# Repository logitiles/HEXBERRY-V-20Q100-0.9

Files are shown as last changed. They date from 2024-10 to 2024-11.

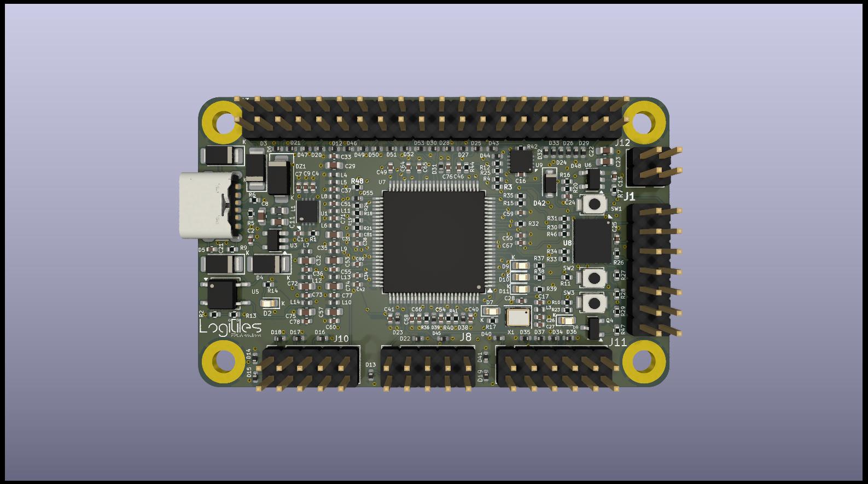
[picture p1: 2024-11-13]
3D e CAM/HEXBERRY-V-20Q100-3D1.jpg

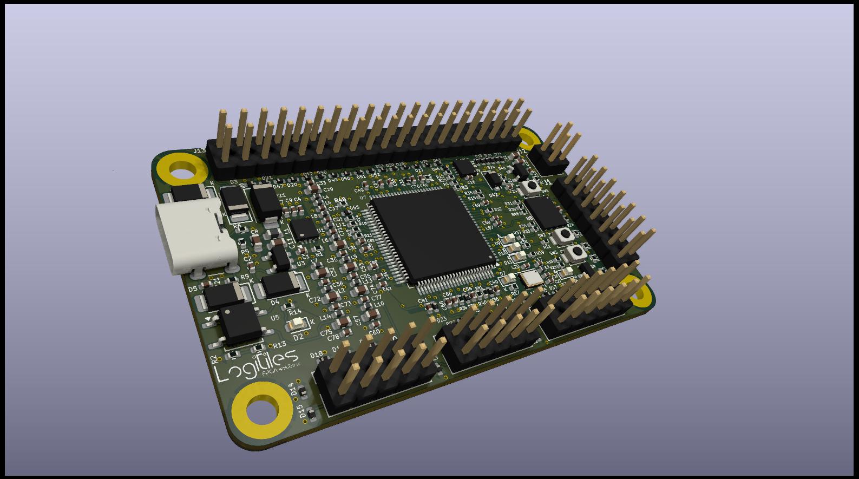
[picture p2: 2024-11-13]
3D e CAM/HEXBERRY-V-20Q100-3D2.jpg

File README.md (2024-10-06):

### <div align="center">We are the [LOGITILES](http://www.logitiles.com), a passionate, full-time FPGA platforms developers team.</div>

- We’re currently working on [HEXCAPE-V Open Source FPGA platform](https://www.hexberryv.eu)

- We’re also currently providing VHDL and VERILOG training and courses for professionals and
 employees.

- Please visit our [Website platform](https://www.logitiles.com)

<br/>

## Our Skill Set
<table><tr><td valign="top" width="33%">

### Electronics design
<div align="center">
<a href="https://www.kicad.org" target="_blank">Kicad</a>
</div>

</td><td valign="top" width="33%">

### Firmware languages & tools
<div align="center">
<a href="https://www.android.com/" target="_blank">Android</a>
<a href="https://www.arduino.cc/" target="_blank">Arduino</a>
<a href="https://www.bell-labs.com/usr/dmr/www/chist.html" target="_blank">C</a>
<a href="https://en.wikipedia.org/wiki/C_Sharp_(programming_language)" target="_blank">C#</a>

<a href="https://dart.dev/" target="_blank">Dart</a>

<a href="https://www.djangoproject.com/" target="_blank">Django framework</a>

<a href="https://go.dev/" target="_blank">Go</a>

<a href="https://simple.wikipedia.org/wiki/JavaScript/" target="_blank">Javascript</a>

<a href="https://kotlinlang.org/" target="_blank">Kotlin</a>

<a href="https://www.opencv.org" target="_blank">OpenCV</a>
<a href="https://pytorch.org" target="_blank">Pytorch</a>

<a href="https://www.raspberrypi.com/" target="_blank">Raspberry PI</a>

<a href="https://www.scala-lang.org/" target="_blank">Scala</a>

<a href="https://www.tensorflow.org" target="_blank">Tensorflow</a>

<a href="https://www.cplusplus.com/" target="_blank">C++</a>
<a href="https://www.javascript.com/" target="_blank">JavaScript</a>
<a href="https://www.php.net/" target="_blank">PHP</a>
<a href="https://www.linux.org/" target="_blank">Linux</a>
<a href="https://www.python.org/" target="_blank">Python</a>
<a href="https://github.com/" target="_blank">Git</a>

</div>

</td><td valign="top" width="33%">

### Fpga brands
<div align="center">
<a href="https://www.altera.com/" target="_blank">Altera</a>

<a href="https://www.amd.com/en/products/adaptive-socs-and-fpgas/fpga.html" target="_blank">Amd</a>

<a href="https://www.latticesemi.com" target="_blank">Lattice semiconductors</a>

<a href="https://www.microchip.com/en-us/products/fpgas-and-plds/fpgas" target="_blank">Microchip</a>

<a href="https://www.efinixinc.com" target="_blank">Efinix</a>

<a href="https://www.sw.siemens.com/" target="_blank">Mentor</a>

<a href="https://www.aldec.com" target="_blank">Aldec</a>

</div>

</td></tr></table>

<br/>

## Connect with us
<div align="center">
<a href="https://x.com/logitiles" target="_blank">

</a>
<a href="https://www.linkedin.com/in/pierfrancescomariasanti/" target="_blank">

</a>
<a href="https://instagram.com/logitiles" target="_blank">

</a>
<a href="https://www.youtube.com/@logitiles-k9s" target="_blank">

</a>
</div>

<br/>

## Github Stats


<br/>

## Recent Blog Posts
<!-- BLOG-POST-LIST:START -->
If things goes well, this section should automatically be replaced by a list of your blog posts after you commit your readme file.
<!-- BLOG-POST-LIST:END -->

<br/>

<br/>

<div align="center">

</div>

<br/>

<br />

----

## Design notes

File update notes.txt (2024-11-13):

 
0.90 to 0.91 vers  (2024/11/13)

- metallized holes to be put in place of the non-metallic ones
- K (cathode) on D1 placed near the other pad
- U1: put pin 3 at 5V and not at PWR_EN
- add 10K pull-up on RESET_N of U6
- reduce R16 to 10k
- put 10K between VCCIO1A_1B_1C and CDONE

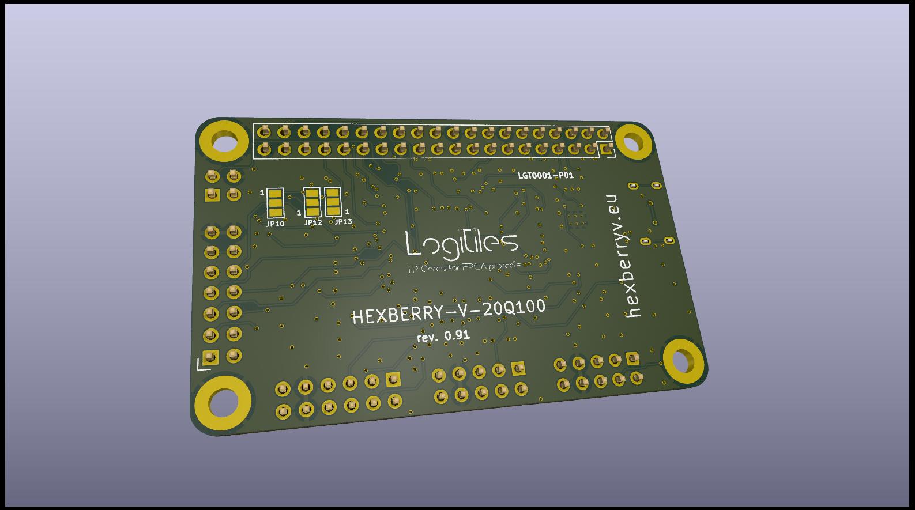
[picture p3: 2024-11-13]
3D e CAM/HEXBERRY-V-20Q100-3D4.jpg

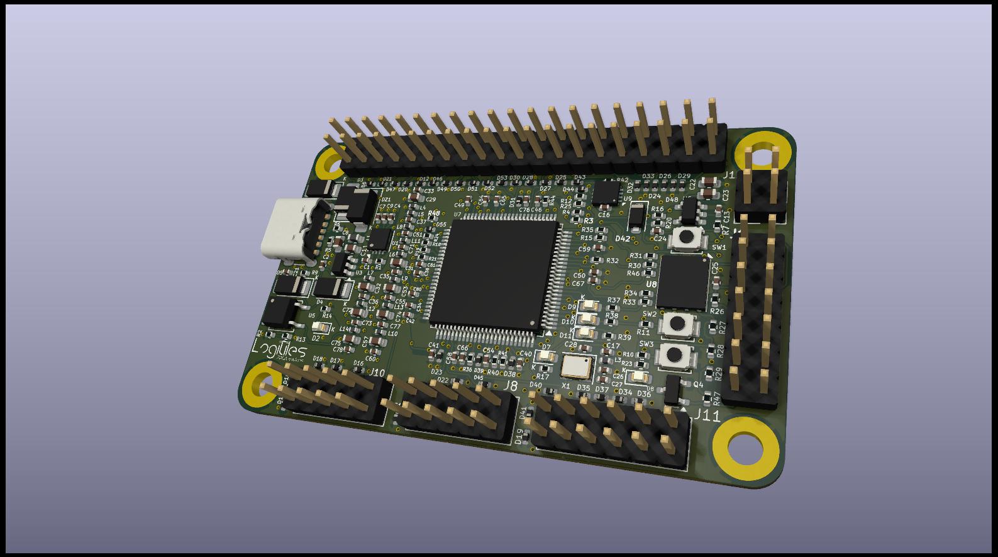
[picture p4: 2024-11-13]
3D e CAM/HEXBERRY-V-20Q100-3D3.jpg

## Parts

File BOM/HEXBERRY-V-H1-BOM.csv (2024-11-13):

Reference | Value | Footprint | Qty | Manufacturer | I° source code | price I° source | II° source code | price II° source
C1,C2,C7,C33,C35,C36,C37,C51,C55,C60,C71,C73,C77,C78 | 1uF | Capacitor_SMD:C_0402_1005Metric | 14 | SAMSUNG | L C14445 | € 0.0016
C4,C9,C13,C16,C17,C21,C25(DNP),C27,C34,C38,C40,C41,C42,C46,C49,C50,C54,C58,C59,C64,C65,C66,C67,C76,C80,C81 | 0.1uF | Capacitor_SMD:C_0402_1005Metric | 25 | CCTC | L C392963 | € 0.0009
C8,C11,C22,C23,C29,C31,C32,C53,C57,C72,C74,C75 | 10uF | Capacitor_SMD:C_0603_1608Metric | 12 | SAMSUNG | L C19702 | € 0.0051
C24 | 0.01uF | Capacitor_SMD:C_0402_1005Metric | 1 | SAMSUNG | L C15195 | € 0.0012
C26,C28 | 4.7uF | Capacitor_SMD:C_0402_1005Metric | 2 | SAMSUNG | L C23733 | € 0.0049
D1,D3,D4, D5 (DNP) | STPS360AF | Diode_SMD:D_SOD-128 | 3 | ST | L C5268312 | € 0.2213 | M 511-STPS360AF
D2,D8 | LS Q976.01-N1Q2-1 | LED_0603 GIALLO VERDE | 2 | YONGYUTAI | L C22371297 | € 0.0076
D11,D10,D9 | LS Q976.01-N1Q2-1 | LED_0603 BLUE | 3 | YONGYUTAI | L C19171394 | € 0.0049
D7 | LS Q976.01-N1Q2-1 | LED_0603 ROSSO | 1 | YONGYUTAI | L C19171390 | € 0.0049 | M 720-LSQ976.01-N1Q2-1
D6,D12,D13,D14,D15,D16,D17,D18,D19,D20,D21,D22,D23,D24,D25,D26,D27,D28,D29,D30,D31,D32,D33,D34,D35,D36,D37,D38,D39,D40,D41,D43,D44,D45,D46,D47,D48,D49,D50,D51,D52,D53,D55 | CPDQC3V3C-HF | diodo_mio:D_0402_1005Metric | 43 | LEIDITECH | L C5128403 | € 0.019
D42 | SOD4007-MS | Diode_SMD:D_SOD-123F | 1 | MSKSEMI | L C3008061 | € 39,00
DZ1 | SMAJ6.5CA/TR13 | Diode_SMD:D_SMA | 1 |  | L C2926834 | € 0.035
J1 | Conn_02x07_Odd_Even | Connector_PinSocket_2.54mm:PinSocket_2x07_P2.54mm_Vertical | 1
J2 | DEALON USB-TYPE-C-010 | Connector_USB:USB_C_Receptacle_GCT_USB4125-xx-x-0190_6P_TopMnt_Horizontal | 1 | DEALON | L C2927030 | € 0.0312
J8,J10 | Conn_02x05_Odd_Even | Connector_PinSocket_2.54mm:PinSocket_2x05_P2.54mm_Vertical | 2
J11 | Conn_02x06_Odd_Even | Connector_PinSocket_2.54mm:PinSocket_2x06_P2.54mm_Vertical | 1
J12 | Conn_02x02_Odd_Even | Connector_PinHeader_2.54mm:PinHeader_2x02_P2.54mm_Vertical | 1
J13 | ZERO 40pin CONN | Connector_PinSocket_2.54mm:PinSocket_2x20_P2.54mm_Vertical | 1
L1 | 33Ohm 4A | Inductor_SMD:L_0603_1608Metric | 1 | Murata | L C98303
L3,L4,L5,L6,L7,L8,L9,L10,L11,L12,L13,L14 | BLM15AX601SZ1D | Inductor_SMD:L_0402_1005Metric | 12 | Murata | L C76886 | € 0.006
Q4 | MMUN2211LT1G | Package_TO_SOT_SMD:SOT-23 | 1 | Onsemi | L C55059 | € 0.0225
R1,R2,R5,R6,R12,R13,R25 | 5K1 | Resistor_SMD:R_0402_1005Metric | 7 | UNI ROYAL | L C25905 | € 0.0005
R9,R20 | 330R | Resistor_SMD:R_0402_1005Metric | 2 |  | L C25104 | € 0.0006
R7, R10, R11, R15, R16, R18, R21, R26, R27, R28, R29, R40, R41, R46, R47, R48, R19(DNP), R31(DNP), R32(DNP), R33(DNP), R34(DNP), R35(DNP) | 10K | Resistor_SMD:R_0402_1005Metric | 16 | YAGEO | L C60490 | € 0.0005
R14,R17,R23,R24,R37,R38,R39 | 1K | Resistor_SMD:R_0402_1005Metric | 16 |  | L C11702 | € 0.0005
R3(DNP),R4(DNP),R30,R42,R44 | 0R0 | Resistor_SMD:R_0402_1005Metric | 17 | UNI ROYAL | L C21376 | € 0.0004
R36 | 100R | Resistor_SMD:R_0402_1005Metric | 19 |  | L C25076 | € 0.0005
SW1,SW2,SW3 | TACT_SW | Button_Switch_SMD:SW_SPST_B3U-1000P | 20 |  | L C231329 | € 0.13 | M 653-B3U-1000P | € 0,91
U1 | MCP1725T-1202E/MC | Package_DFN_QFN:DFN-8-1EP_3x3mm_P0.5mm_EP1.65x2.38mm_ThermalVias | 21 |  | L C623071 | € 0.57 | M 579-MCP1725T-1202EMC | € 0,66 | D MCP1725T-1202E/MCCT-ND | € 0.65
U3 | SPX3819M5-L-3-3 | Package_TO_SOT_SMD:SOT-23-5 | 22 |  | L C20617301 | € 0,076
U5 | GAQY212GSX | Package_SO:SOP-4_3.8x4.1mm_P2.54mm | 23 |  | L C19271988 | € 0.4191
U6 | TLV840MADL13DBVR | Package_TO_SOT_SMD:SOT-23-5 | 24 |  | L C1518734 | € 0.5085 | M 595-TLV840MADL13DBVR | € 0,66 | D 296-TLV840MADL13DBVRCT-ND | € 0.51
U7 | T20Q100F3C3 | Package_QFP:LQFP-100_14x14mm_P0.5mm | 25 |  | D 2134-T20Q100F3C3-ND | € 8.5
U8(DNP) | W25Q32JVUUIQ | Package_SON:WSON-8-1EP_4x4mm_P0.8mm_EP1.98x3mm | 26 |  | L C2999380 | € 0.42 | M 454-W25Q32JVXGIQTR | € 0,79
U9 | ATSHA204A-MAHDA-T | Package_DFN_QFN:TDFN-8-1EP_3x2mm_P0.5mm_EP1.4x1.4mm | 27 |  | L C461613 | € 0.7052 | M 566-ATSHA204AMAHDA-T0,52 € | € 0,52 | D ATSHA204A-MAHDA-TCT-ND | € 0.52
X1 | ASE-50.000MHz-ET | Oscillator:Oscillator_SMD_Abracon_ASE-4Pin_3.2x2.5mm | 28 |  | L C5885439 | € 0.24 | 535-ASE-50.000MHZ-E-TCT-ND | € 0,85 | D 535-ASE-50.000MHZ-E-TTR-ND | € 0.85
LEGEND:
L: LCSC
D: DIGIKEY
M: MOUSER

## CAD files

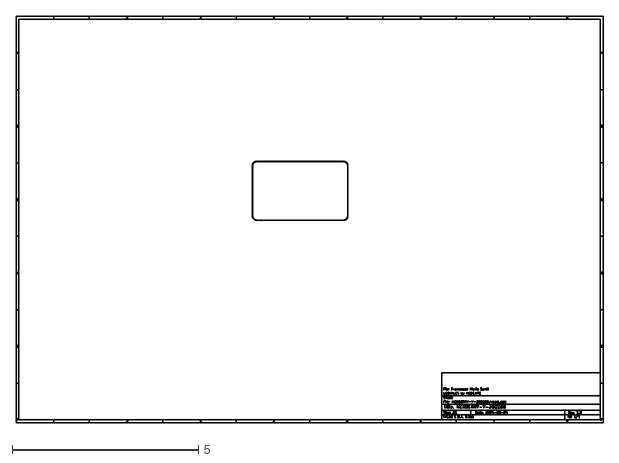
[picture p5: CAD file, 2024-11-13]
PM/STENCIL/HEXBERRY-V-20Q100-Edge_Cuts.dxf
15.7 x 10.9

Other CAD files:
PM/STENCIL/HEXBERRY-V-20Q100-F_Paste.dxf

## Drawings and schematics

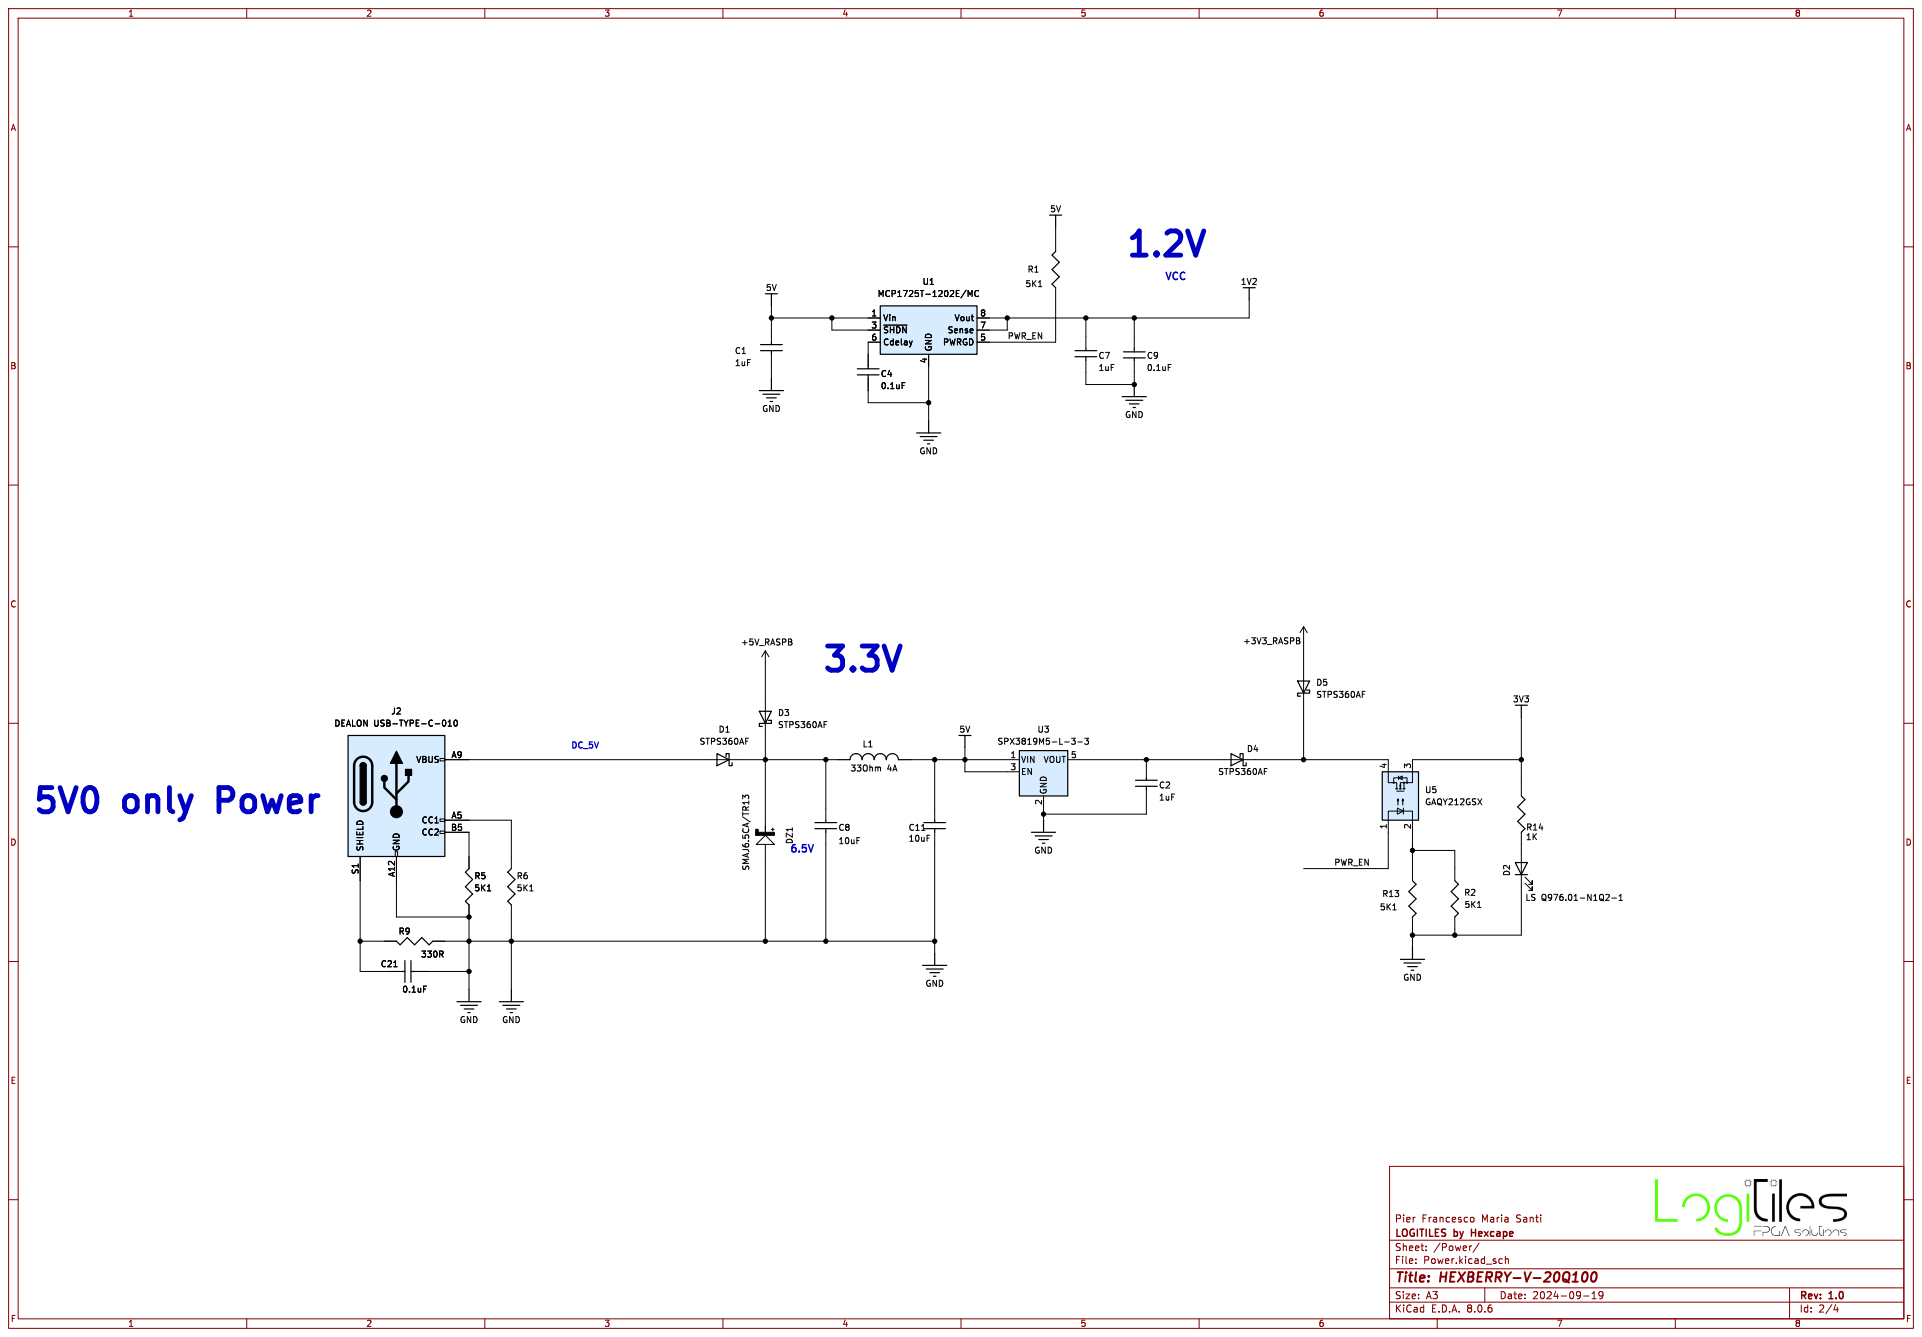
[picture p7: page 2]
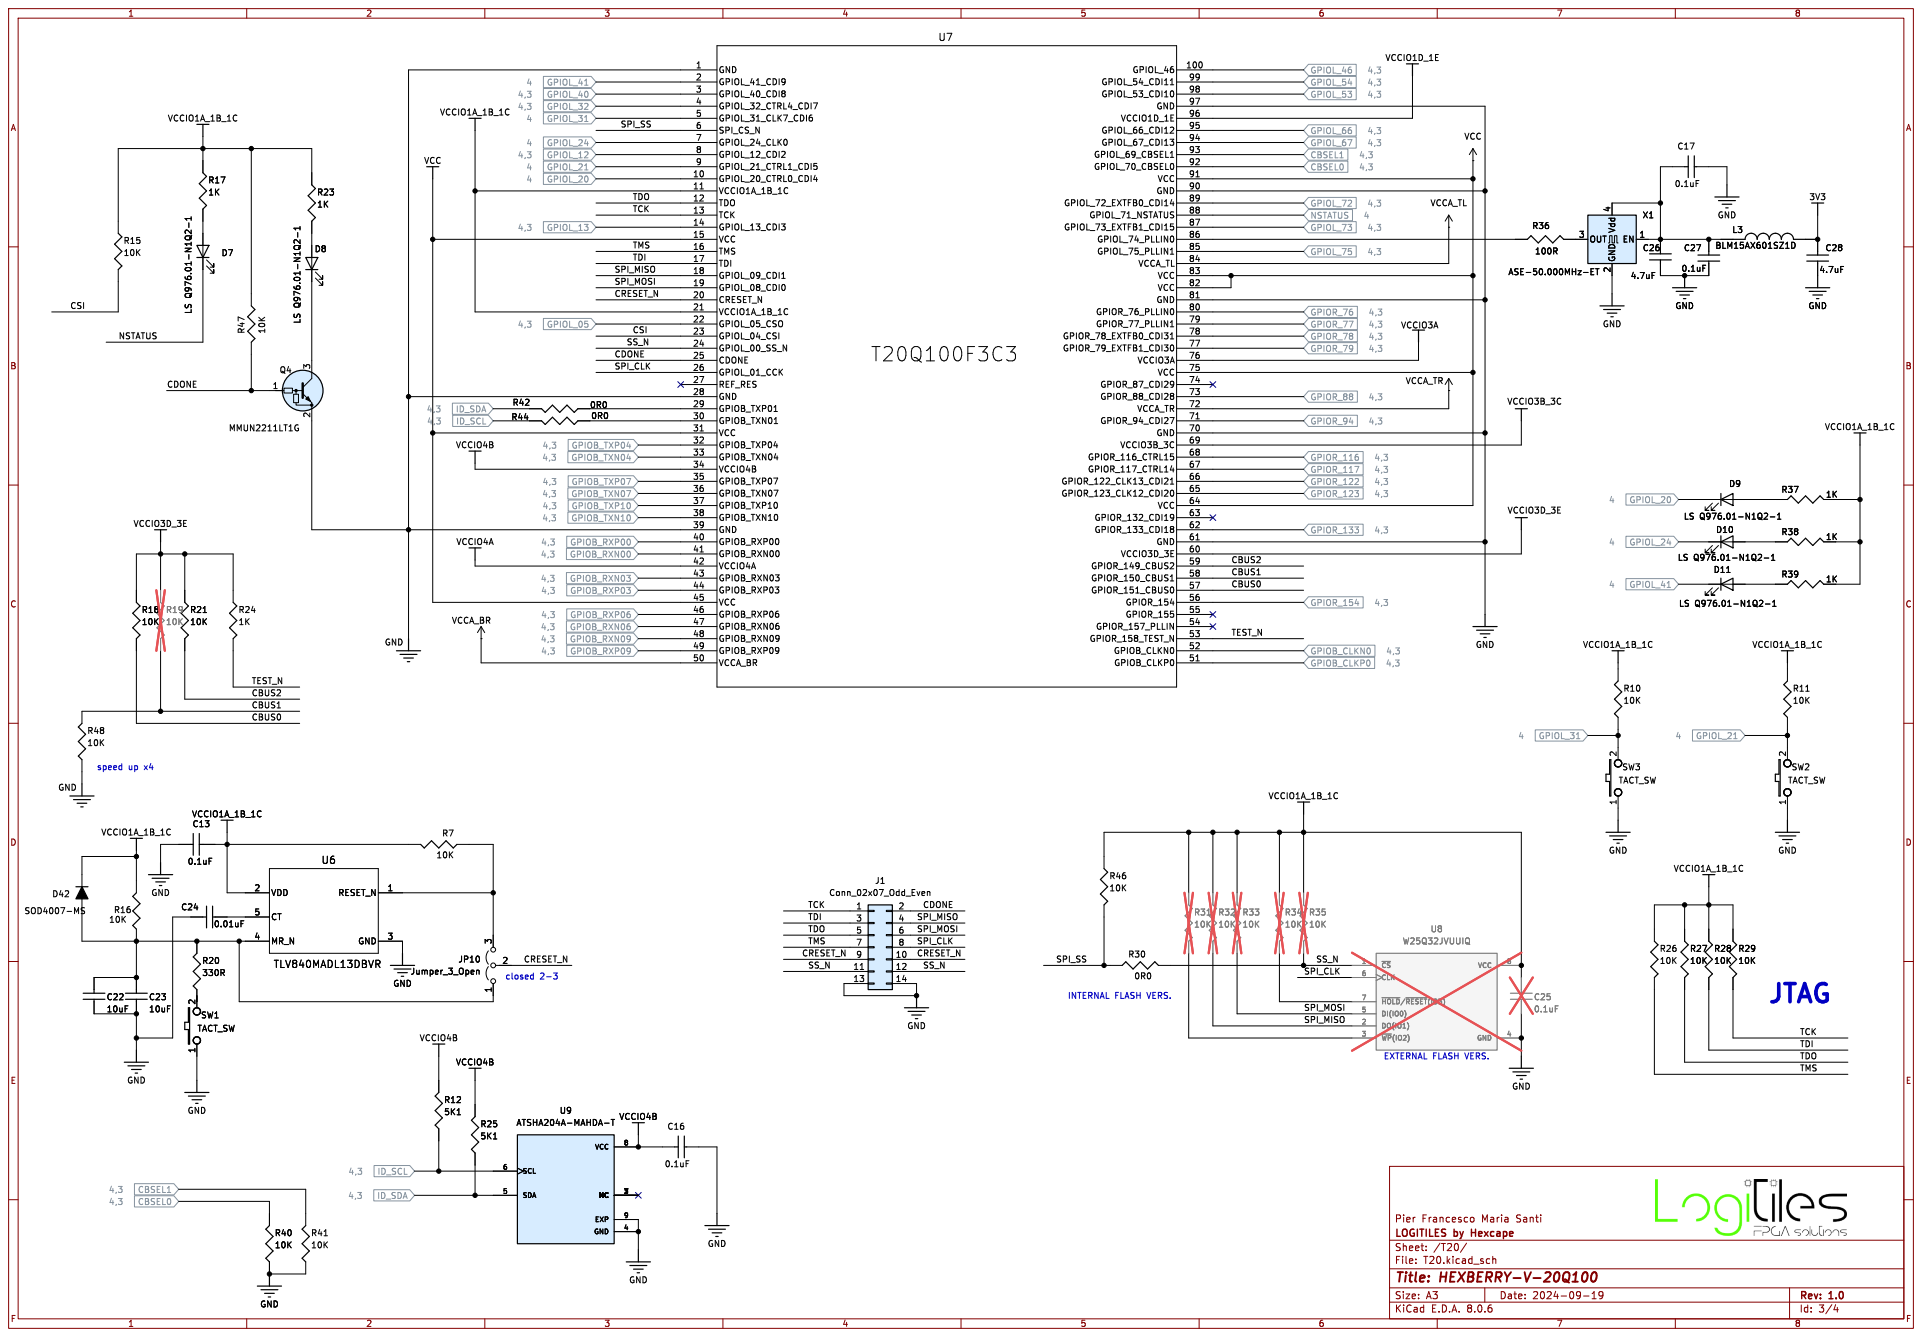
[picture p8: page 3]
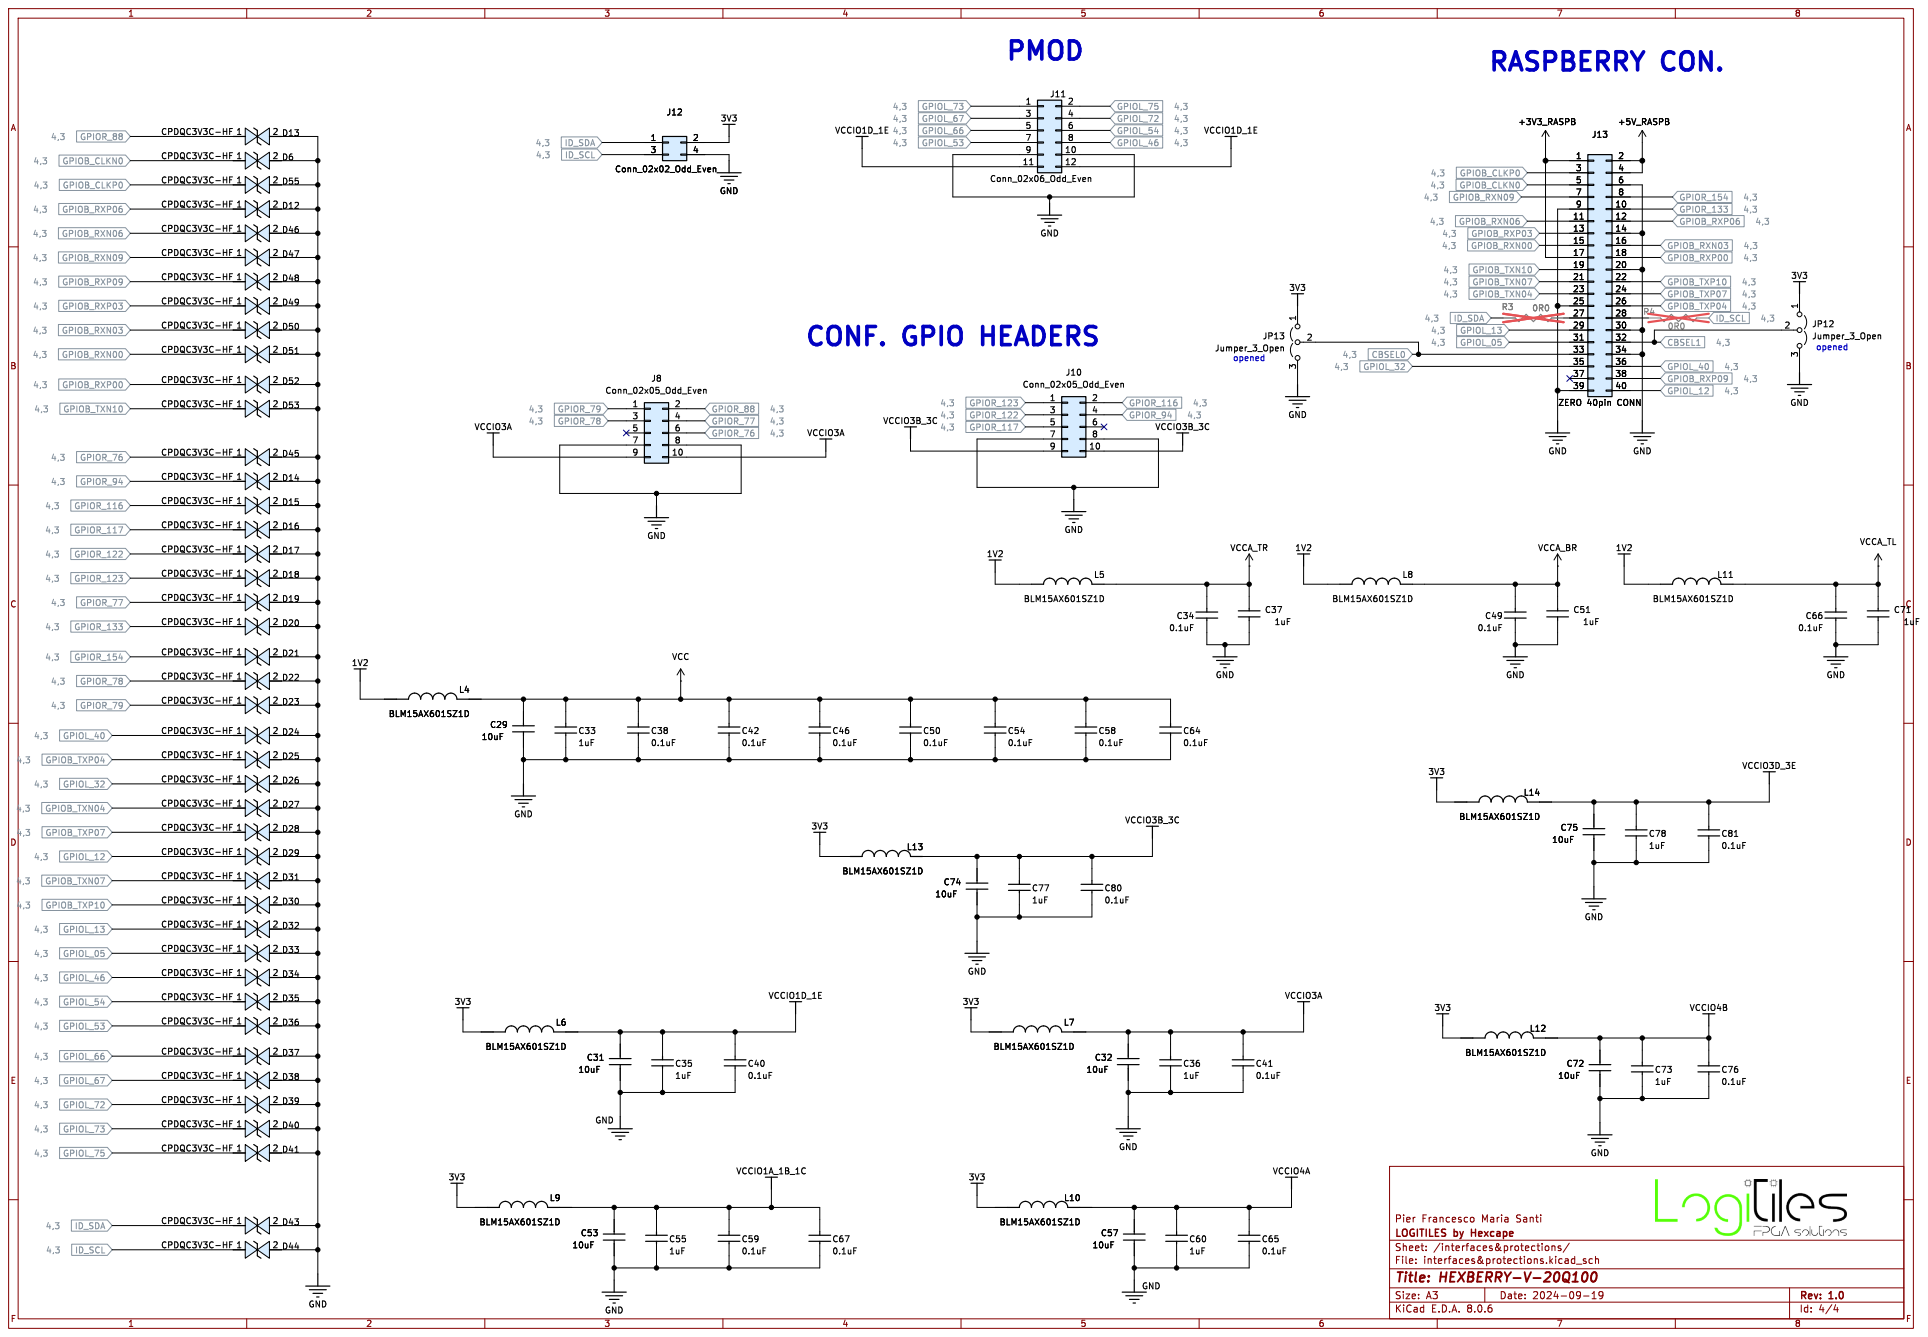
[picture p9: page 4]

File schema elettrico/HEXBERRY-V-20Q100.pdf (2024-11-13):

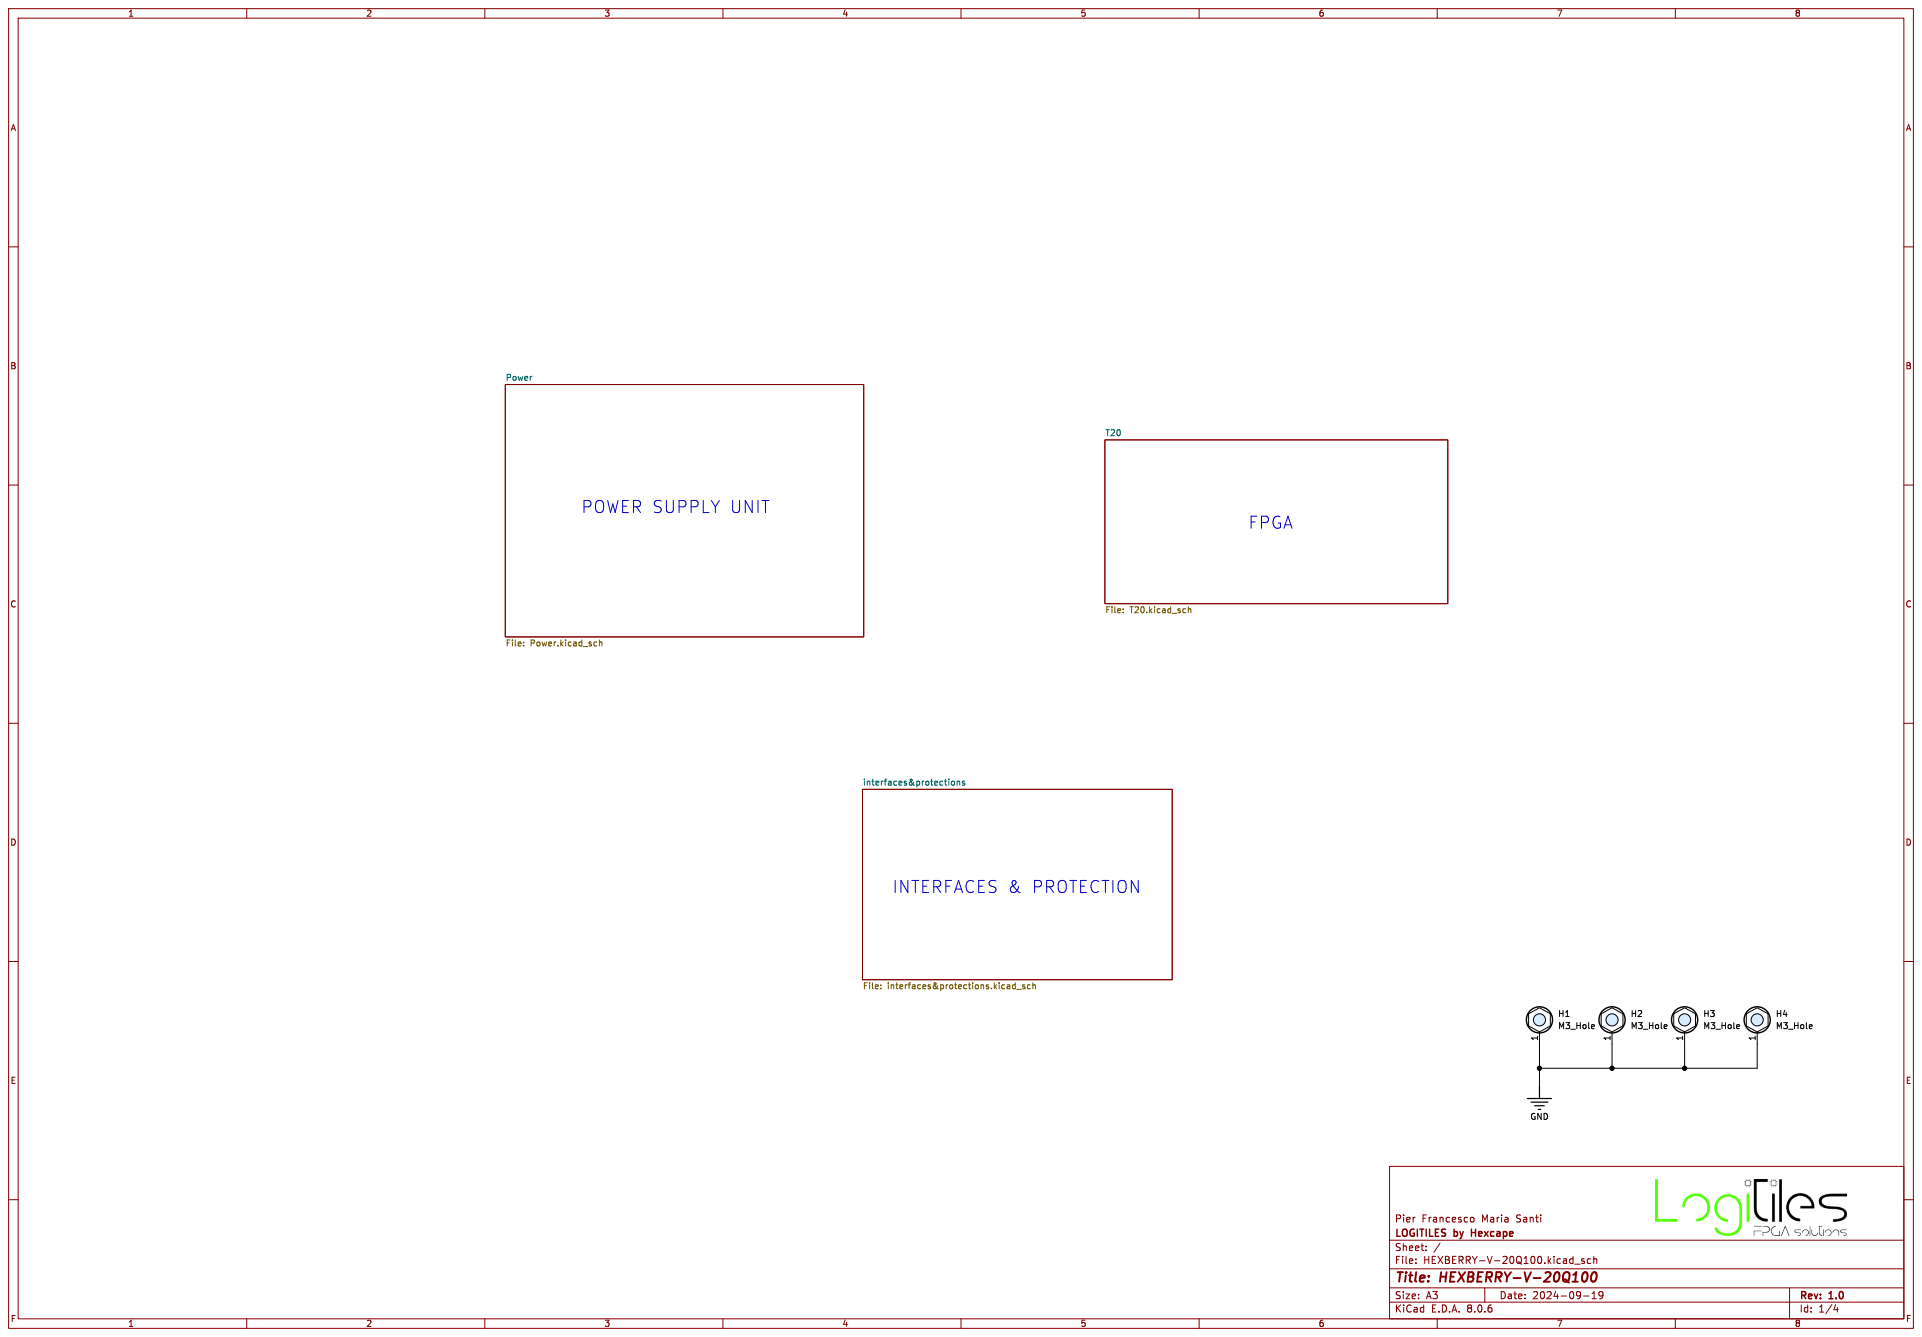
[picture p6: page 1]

interfaces&protections File: interfaces&protections.kicad_sch
